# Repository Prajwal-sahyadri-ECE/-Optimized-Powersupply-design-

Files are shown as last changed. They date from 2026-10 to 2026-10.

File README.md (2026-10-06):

# Optimized Power Supply & Battery Management System (ICS)

## Overview

This project is an optimized, high-efficiency **Power Management and Multi-Cell Battery Protection System** designed for Industrial Control Systems (ICS) and embedded hardware architectures. The system integrates a **5V Step-Down Switching Regulator**, an **Integrated Li-Ion/LiPo Charger Power Management IC (PMIC)**, and a dedicated **Multi-Cell Battery Monitor & Protection IC** to deliver reliable power regulation, fault protection, and uninterrupted system operation.

---

## Technical Specifications & Architecture

### 1. Buck DC-DC Voltage Regulator (`U1`: LM2596S-5)

* **Function:** High-efficiency step-down DC-DC conversion supplying a stable 5V system rail.
* **Key Components:**
* **Inductor (`L1`):** $33\,\mu\text{H}$ power inductor optimized for switching output ripple filtering.
* **Catch Diode (`D1`):** SS54 Schottky diode for efficient freewheeling action.
* **Capacitors (`C1`, `C2`):** $680\,\mu\text{F}$ input bulk capacitor and $220\,\mu\text{F}$ output smoothing capacitor.

### 2. Power Management & Charger IC (`U2`: IP2326)

* **Function:** Integrated power-path management and lithium battery charging controller.
* **Key Features:**
* **Power Inductor (`L2`):** $2.2\,\mu\text{H}$ low-DCR inductor for high-efficiency charge buck/boost stages.
* **Decoupling/Filter Network:** Output and input ceramic filter capacitors (`C3`, `C5`, `C6` — $10\,\mu\text{F}$ / $22\,\mu\text{F}$).
* **Thermal Monitoring:** External NTC thermistor interface (`TH1` - $100\text{k}\Omega$) for battery over-temperature protection.
* **Status Indication:** Integrated LED indicator (`LED3` / KPT-1608EC) for charging status output.

### 3. Multi-Cell Battery Protection & Monitoring (`U3`: BQ7791500PWR)

* **Function:** Advanced hardware protection for multi-cell Lithium-ion/LiFePO4 battery packs.
* **Key Features:**
* **Cell Balancing & Sensing:** Multi-channel cell tap connections (`VC0`–`VC5`) paired with filter RC networks (`R10`–`R12`, `C10`–`C13`).
* **Charge/Discharge Protection MOSFETs:** Dual high-side/low-side N-channel MOSFET switching control (`Qchg1` & `Qdis1` - IRLR7843TRPBF) driven by high-voltage gate circuitry.
* **Current Sensing:** Low-resistance high-precision current sense resistor (`RCS1` - CRA2512 series) for overcurrent and short-circuit protection.
* **Thermal Sensing:** Onboard NTC thermistor input (`TH3` - $10\text{k}\Omega$) for cell-level temperature monitoring.

### 4. Input/Output Interfaces & Protection

* **Connectors:**
* `J1`: DC Barrel Jack input ($54\text{-}00133$).
* `J2`: Screw terminal output header ($1\times2$).
* `J3`: Multi-pin screw terminal block for battery pack tap/connection interfaces (`B+`, `B-`, `PACK+`, `PACK-`).

* **Overcurrent Protection:** Inline board-level input/output protection fuse (`F1`).
* **Tactile Control Switches:** Push buttons (`S1`, `S2`, `S3`, `S4` - EVP-BB1AAB000) for system control/wake function.
* **Status Indicators:** Diagnostics LEDs (`LED1`, `LED2` - KP-1608SGC) with current-limiting resistors (`R17`, `R22`).

---

## PCB Design & Layout Details

* **Board Type:** 2-Layer High-Density Interconnect PCB.
* **Top Layer:** Signal routing, IC power pads, switching nodes (`LX`, `SW`), and ground copper pouring for optimal thermal dissipation.
* **Bottom Layer:** Solid ground plane return paths and secondary trace routing.
* **Thermal Management:** Exposed thermal ground pads with dense via arrays under `U1`, `U2`, and `U3` to sink heat across layers.
* **High-Current Paths:** Widened power traces for input voltage rails, ground pads, and MOSFET drain/source connections to minimize $I^2R$ conduction losses.

---

```text
├── Hardware/
│   ├── Schematic/
│   │   └── Power Circuit.kicad_sch
│   ├── Layout/
│   │   ├── PCB top layer.png
│   │   ├── PCB bottom layer.png
│   │   └── Power Circuit.kicad_pcb
│   └── Gerber/
│       └── Gerber_Files.zip
├── 3D/
│   └── 3D-view.png
├── LICENSE
└── README.md

```

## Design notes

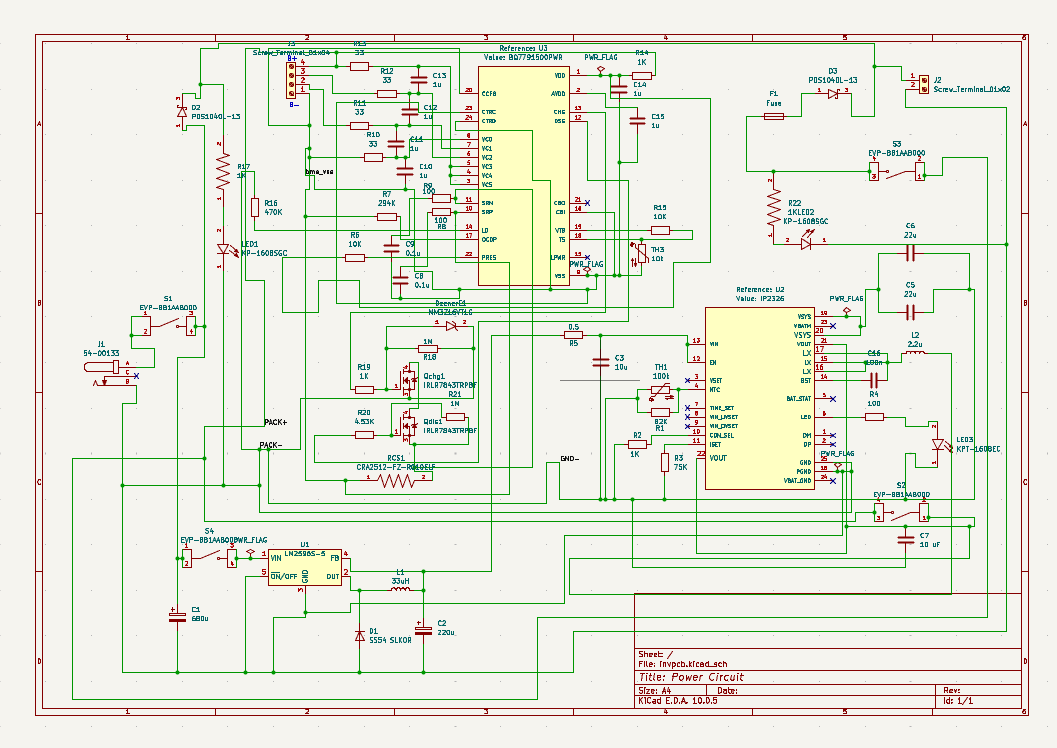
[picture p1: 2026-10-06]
PCB Schematic.png

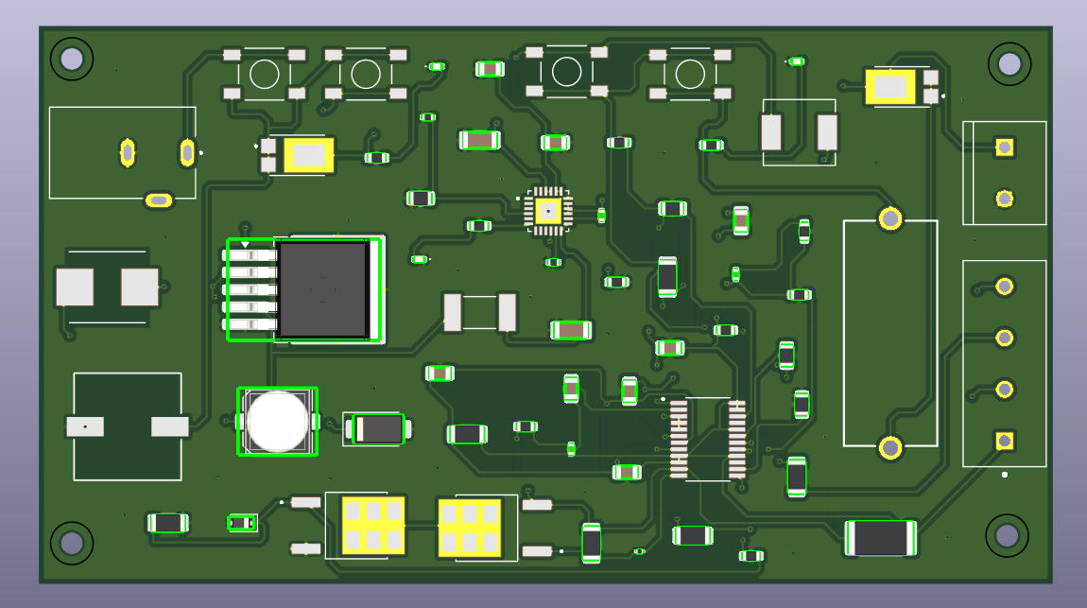
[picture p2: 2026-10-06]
3D-View.png

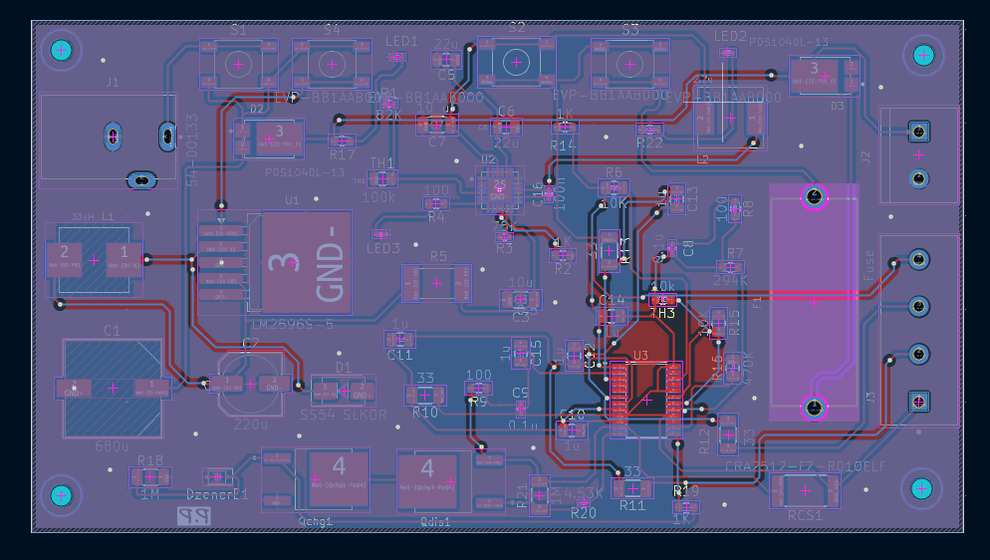
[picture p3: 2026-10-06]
PCB bottom layer.png

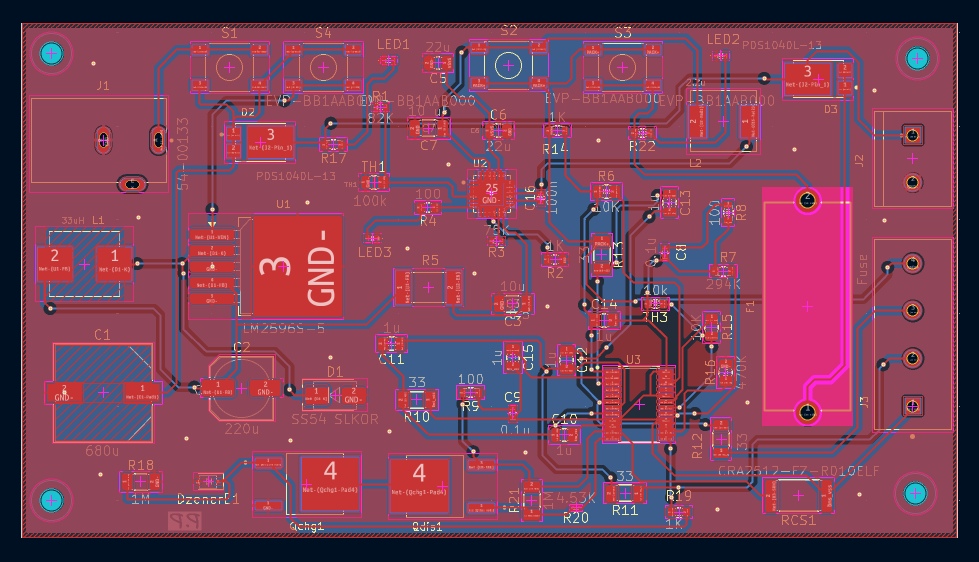
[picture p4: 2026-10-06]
PCB top layer.png

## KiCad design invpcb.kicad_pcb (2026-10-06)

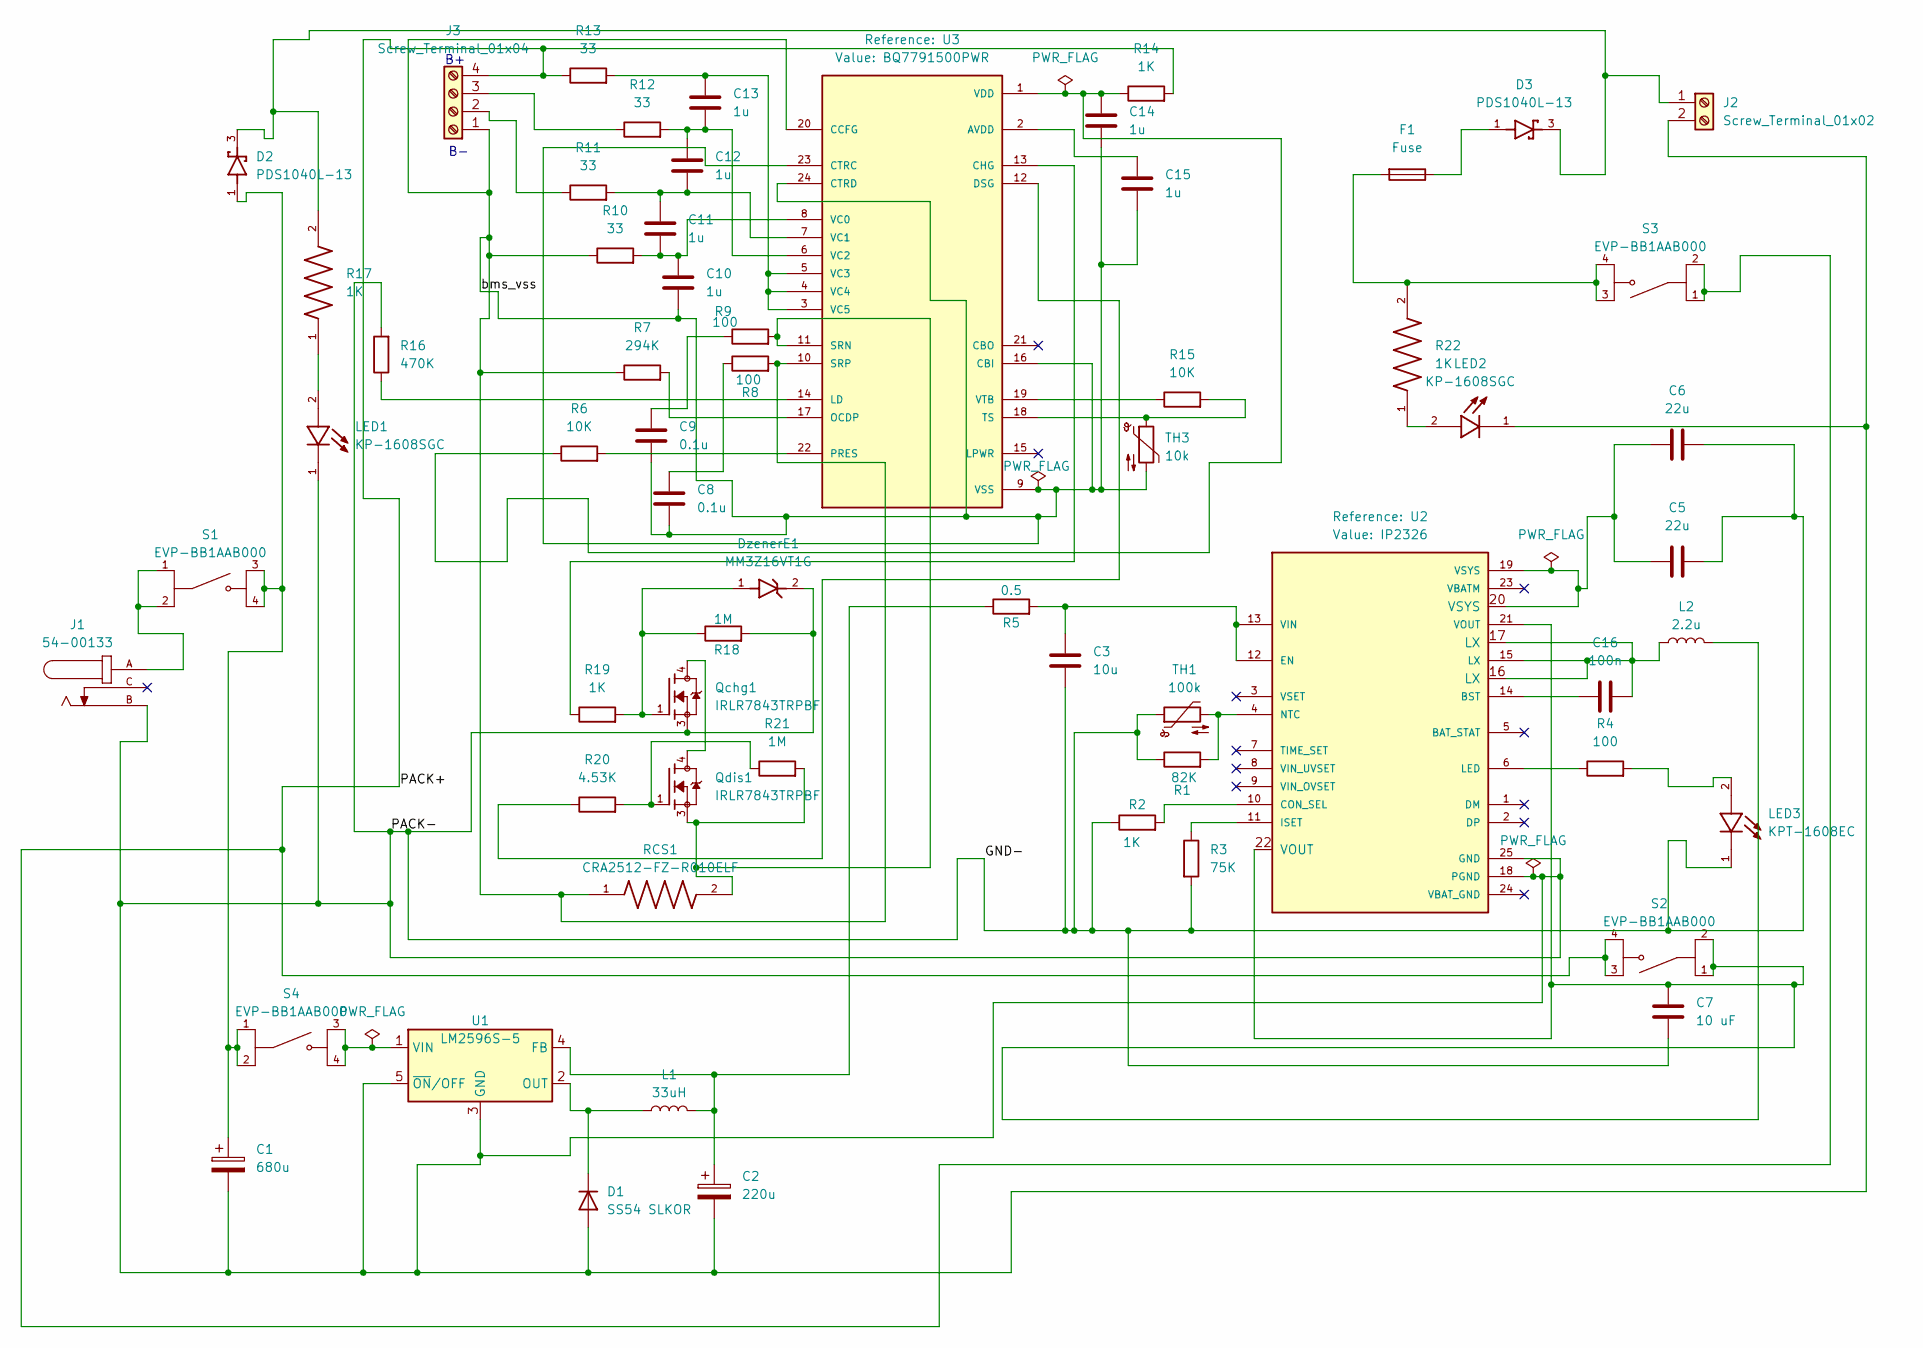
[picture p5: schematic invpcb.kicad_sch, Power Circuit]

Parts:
C1: 680u; CHEMI-JA0
C2: 220u; C_Elec_6.3x7.7
C3: 10u; C_1206_3216Metric
C5, C6: 22u; C_0805_2012Metric
C7: 10 uF; C_1206_3216Metric
C8, C9: 0.1u; C_0402_1005Metric
C10, C11, C12, C13, C14, C15: 1u; C_0805_2012Metric
C16: 100n; C_0402_1005Metric
D1: SS54 SLKOR; D_SMA
D2, D3: PDS1040L-13; DIO_PDS1040L-13
DzenerE1: MM3Z16VT1G; D_SOD-323
F1: Fuse; 696101000002
J1: 54-00133; TENSILITY_54-00133
J2: Screw_Terminal_01x02; 2pin terminal TE_282837-2
J3: Screw_Terminal_01x04; TE_282837-4
L1: 33uH; IND_ETQP5M330YFM
L2: 2.2u; IND_SPM6530T-2R2M
LED1, LED2: KP-1608SGC; LED_0402_1005Metric
LED3: KPT-1608EC; LED_0402_1005Metric
Qchg1: IRLR7843TRPBF; TO229P990X239-3_4N
Qdis1: IRLR7843TRPBF; TO229P990X239-3_4N
R1: 82K; R_0402_1005Metric
R2, R14, R17, R19, R22: 1K; R_0603_1608Metric
R3: 75K; R_0402_1005Metric
R4, R8, R9: 100; R_0603_1608Metric
R5: 0.5; RES_RCWE2512R500FKEA
R6, R15: 10K; R_0805_2012Metric
R7: 294K; R_0603_1608Metric
R10, R11, R12, R13: 33; R_1206_3216Metric
R16: 470K; R_0805_2012Metric
R18, R21: 1M; R_1206_3216Metric
R20: 4.53K; R_0201_0603Metric
RCS1: CRA2512-FZ-R010ELF; R_2512_6332Metric
S1, S2, S3, S4: EVP-BB1AAB000; SW_PTS525SM15SMTR2LFS
TH1: 100k; R_0805_2012Metric
TH3: 10k; R_0603_1608Metric
U1: LM2596S-5; TO-263-5_TabPin3
U2: IP2326; ip2326 QFN50P400X400X80-25N
U3: BQ7791500PWR; SOP65P640X120-24N; PARTREV H; DigiKey_Part_Number 296-50995-1-ND

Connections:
/GND-: C1.2, C2.2, C3.2, C5.2, C6.2, C7.2, D1.2 (A), DzenerE1.2, J1.B, J2.2, LED1.1, LED2.1, LED3.1, Qchg1.3, R1.1, R2.1, R3.2, R16.2, R18.2, TH1.1, U1.3 (GND), U1.5 (~ON/OFF), U2.18 (PGND), U2.25 (GND)
/PACK+: J3.4, R13.1, R14.2, S2.3, S2.4, S3.1, S3.2
/bms_vss: C8.2, C9.2, C10.2, C14.2, C15.2, J3.1, R7.1, R8.2, R10.1, RCS1.1, TH3.2, U3.9 (VSS), U3.10 (SRP), U3.16 (CBI), U3.20 (CCFG), U3.23 (CTRC), U3.24 (CTRD)
unnamed: C1.1, D2.1, D2.2, S1.3, S1.4, S4.1, S4.2
unnamed: C7.1, L2.2, S2.1, S2.2, U2.21 (VOUT), U2.22 (VOUT)
unnamed: C8.1, R8.1
unnamed: C9.1, R9.1
unnamed: C16.2, L2.1, U2.15 (LX), U2.16 (LX), U2.17 (LX)
unnamed: D1.1 (K), L1.1, U1.2 (OUT)
unnamed: D3.1, D3.2, F1.1
unnamed: DzenerE1.1, Qchg1.1, R18.1, R19.2
unnamed: F1.2, R22.2, S3.3, S3.4
unnamed: J1.A, S1.1, S1.2
unnamed: D2.3, D3.3, J2.1, R17.2
unnamed: J3.2, R11.1
unnamed: J3.3, R12.1
unnamed: LED1.2, R17.1
unnamed: LED2.2, R22.1
unnamed: LED3.2, R4.2
unnamed: Qchg1.4, Qdis1.4
unnamed: Qdis1.1, R20.2, R21.1
unnamed: C2.1, L1.2, R5.1, U1.4 (FB)
unnamed: S4.3, S4.4, U1.1 (VIN)
unnamed: C16.1, U2.14 (BST)
unnamed: R2.2, U2.10 (CON_SEL)
unnamed: C3.1, R5.2, U2.12 (EN), U2.13 (VIN)
unnamed: R3.1, U2.11 (ISET)
unnamed: R4.1, U2.6 (LED)
unnamed: R1.2, TH1.2, U2.4 (NTC)
unnamed: C15.1, U3.2 (AVDD)
unnamed: R19.1, U3.13 (CHG)
unnamed: R20.1, U3.12 (DSG)
unnamed: R16.1, U3.14 (LD)
unnamed: R7.2, U3.17 (OCDP)
unnamed: R6.2, U3.22 (PRES)
unnamed: Qdis1.3, R9.2, R21.2, RCS1.2, U3.11 (SRN)
unnamed: R15.2, TH3.1, U3.18 (TS)
unnamed: C10.1, C11.2, R10.2, U3.8 (VC0)
unnamed: C11.1, C12.2, R11.2, U3.7 (VC1)
unnamed: C12.1, C13.2, R12.2, U3.6 (VC2)
unnamed: C13.1, R13.2, U3.3 (VC5), U3.4 (VC4), U3.5 (VC3)
unnamed: C14.1, R6.1, R14.1, U3.1 (VDD)
unnamed: R15.1, U3.19 (VTB)
VSYS: C5.1, C6.1, U2.19 (VSYS), U2.20 (VSYS)

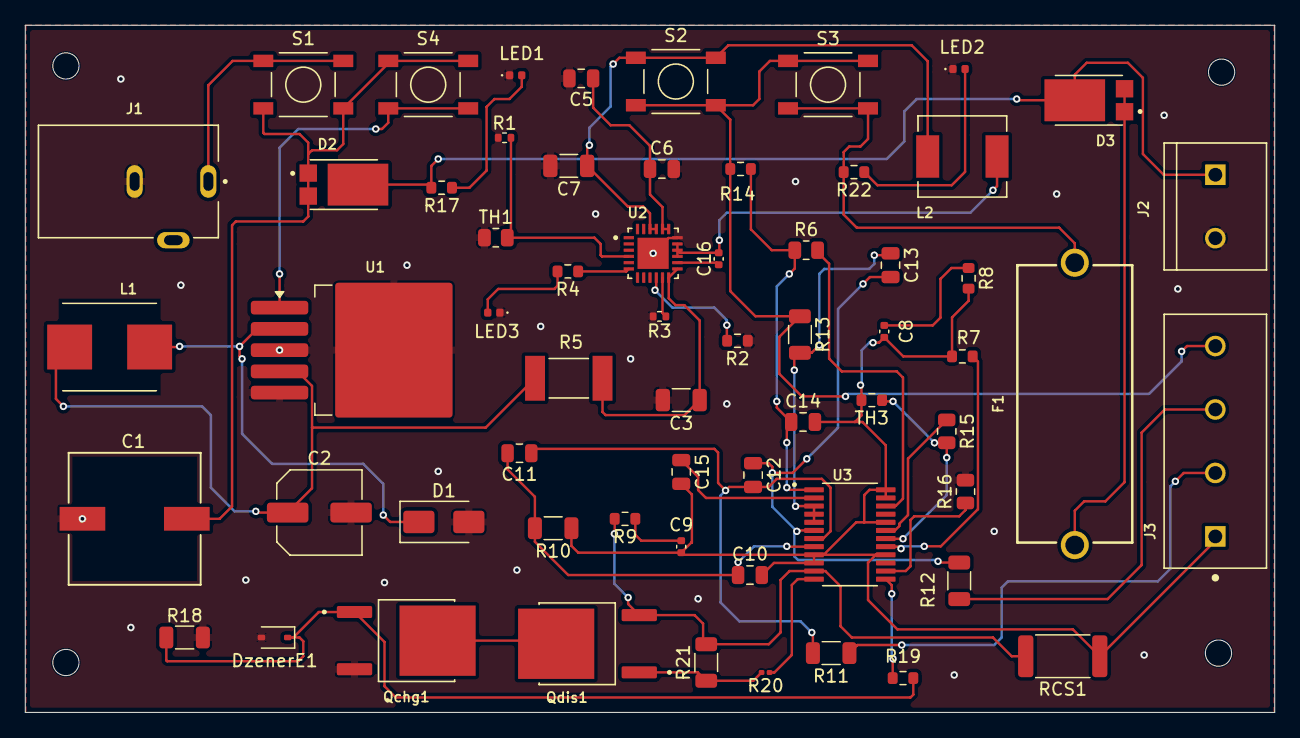
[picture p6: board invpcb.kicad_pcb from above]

Board: 2 copper layers, 100.0 x 55.0 mm, 62 parts (0 on the bottom side), 44 nets.
